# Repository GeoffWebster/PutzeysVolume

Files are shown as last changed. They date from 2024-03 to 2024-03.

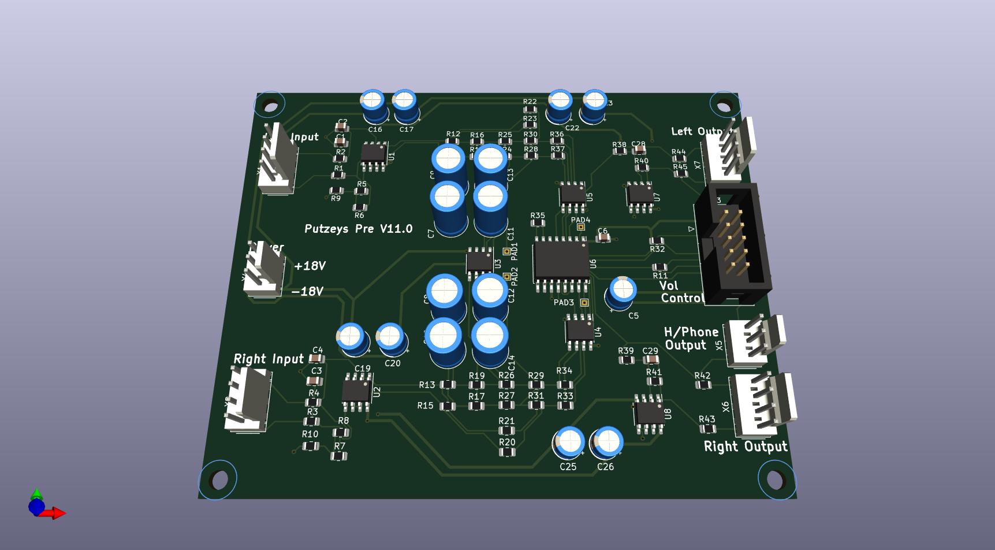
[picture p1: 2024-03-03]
putzeysPre11.jpg

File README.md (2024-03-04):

Bruno Putzeys Balanced Volume Control / MAS6116 Digital Control
===============================================================

KiCad V8 files for Bruno Putzeys Balanced Pre-amp with integrated MAS6116 Digital Volume Control Chip.

Circuit modifications from original design includes
* Addition of MAS6116 digital Stereo Volume Control in place of dual linear 10Kohm potentiometer
* Addition of inverting unity gain amplifier driver for driven signal for - output pin. Original was balanced output impedance only
* Addition of Unbalanced output (X5) to provide input to headphone amplifier

Original Bruno Putzeys preamplifier used qty 4 of LM4562 + qty 1 of TL072 (as servo)
Alternatives to LM4562 include
* OPA1642AIDR  595-OPA1642AIDR
* OPA1656ID    595-OPA1656ID

Addition of inverting amplifiers within balanced output (Vout-) adds following components into overall circuit:
U7, U8 OPA1656
R38-41 12K 0805 Thin Film
C28, C29 47pF **DNF**

Addition of unbalanced output for use by external headphone amplifier added connector X5 only.

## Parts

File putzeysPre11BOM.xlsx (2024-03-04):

Ref | Qty | Value | Mouser Part Number | Footprint | Description
C1, C2, C3, C4 | 4 | 100pF | 603-CC805FRNPO9BN101 | Capacitor_SMD:C_0805_2012Metric | 100pF 0805
C28,C29 | 2 | 47pF | - | Capacitor_SMD:C_0805_2012Metric | 47pF 0805 DNF
C5, C16, C17, C19, C20, C22, C23, C25, C26 | 9 | 22uF 63V | 710-860010572003 | Capacitor_THT:CP_Radial_D5.0mm_P2.00mm | 22uF 63V
C6 | 1 | 220nF | 603-CC0805JRX7R8B224 | Capacitor_SMD:C_0805_2012Metric | 220nF 0805
C7, C8, C9, C10, C11, C12, C13, C14 | 8 | 10uF 50V | 667-ECEA1HN100U | Capacitor_THT:C_Radial_D6.3mm_H11.0mm_P2.50mm | 10uF 50V Unpolarized capacitor
C15, C18, C21, C24, C27, C30, C31 | 7 | 1uF 50v | 603-CC1206JK7R9BB105 | Capacitor_SMD:C_1206_3216Metric | 1uF 1206
R1, R2, R3, R4 | 4 | 100 | 603-RT0805FRD07100RL | Resistor_SMD:R_0805_2012Metric | 100R Thin Film 0805
R5, R6, R7, R8 | 4 | 47K | 660-RK73H2ATTDD4702F | Resistor_SMD:R_0805_2012Metric | 47K 0805
R9, R10 | 2 | 2M2 | 603-AC0805FR-072M2L | Resistor_SMD:R_0805_2012Metric | 2M2 0805
R28, R29, R30, R31 | 4 | 10K | 603-RT0805DRE0710KL | Resistor_SMD:R_0805_2012Metric | 10K Precision Thin Film 0805
R11, R16, R17, R18, R19, R32, R35 | 7 | 10K | 660-RK73H2ATTED1002F | Resistor_SMD:R_0805_2012Metric | 10K 0805
R12, R13, R14, R15 | 4 | 12K | 660-RK73H2ATTD1202F | Resistor_SMD:R_0805_2012Metric | 12K 0805
R38, R39, R40, R41 | 4 | 12K | 603-RT0805DRE0712KL | Resistor_SMD:R_0805_2012Metric | 12K Precision Thin Film 0805
R20, R21, R22, R23, R33, R34, R36, R37 | 8 | 1K | 594-MCU0805MD1001DP5 | Resistor_SMD:R_0805_2012Metric | 1K Precision Thin Film 0805
R24, R25, R26, R27 | 4 | 220K | 660-RK73H2ATTD2203F | Resistor_SMD:R_0805_2012Metric | 220K 0805
R42, R43, R44, R45 | 4 | 22 | 660-RK73H2ATTDD22R0F | Resistor_SMD:R_0805_2012Metric | 22 0805
U1, U2, U4, U5, U7, U8 | 6 | OPA1656ID | 596-OPA1656ID | Package_SO:SOIC-8_3.9x4.9mm_P1.27mm | Alternatives are LM4562, OPA1642
U6 | 1 | MAS6116 |  |  | Available from Profusion (https://eu.profusion.uk/ro/mas6116ea1sa306)
U3 | 1 | TL072 | 595-TL072CDR | Package_SO:SOIC-8_3.9x4.9mm_P1.27mm | TL072
X1, X2, X6, X7 | 4 | 22-23-2041 | 538-22-23-2041 | Connector_Molex:Molex_KK-254_AE-6410-04A_1x04_P2.54mm_Vertical
X3 | 1 | 2-1761603-3 | 571-2-1761603-3 | Connector_IDC:IDC-Header_2x05_P2.54mm_Vertical
X4, X5 | 2 | 22-23-2031 | 538-22-23-2031 | Connector_Molex:Molex_KK-254_AE-6410-03A_1x03_P2.54mm_Vertical

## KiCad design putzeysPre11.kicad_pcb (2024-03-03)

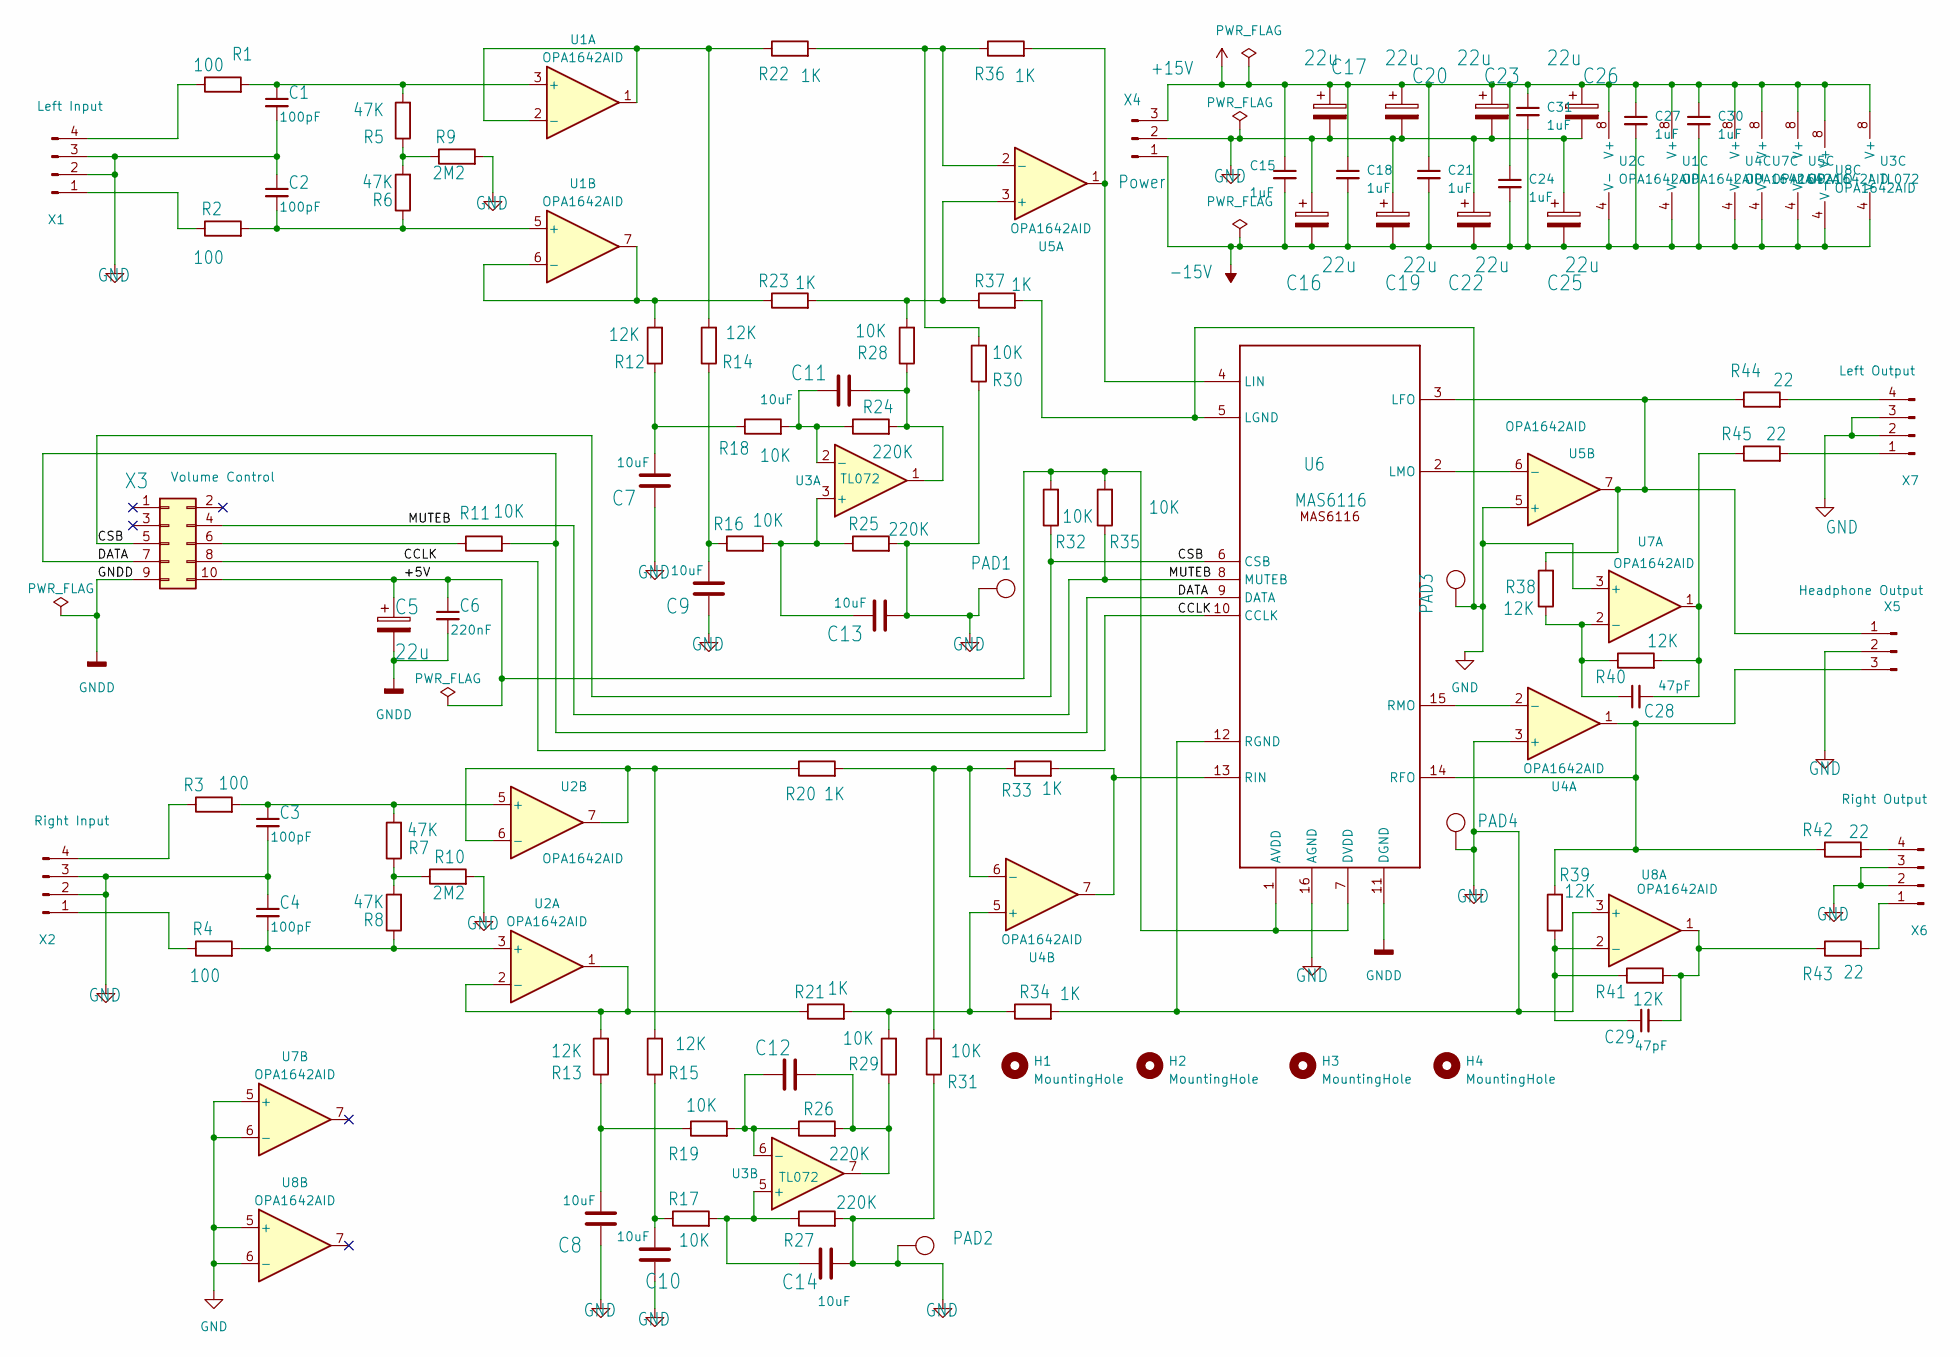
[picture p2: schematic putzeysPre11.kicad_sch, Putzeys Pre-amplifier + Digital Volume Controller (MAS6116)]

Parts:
C1, C2, C3, C4: 100pF; C_0805_2012Metric
C5, C16, C17, C19, C20, C22, C23, C25, C26: 22u; CP_Radial_D5.0mm_P2.00mm
C6: 220nF; C_0805_2012Metric
C7, C8, C9, C10, C11, C13, C14: 10uF; C_Radial_D6.3mm_H11.0mm_P2.50mm
C12: C; C_Radial_D6.3mm_H11.0mm_P2.50mm
C15, C18, C21, C24, C27, C30, C31: 1uF; C_1206_3216Metric
C28, C29: 47pF; C_0805_2012Metric
H1, H2, H3, H4: MountingHole; MountingHole_3.2mm_M3
PAD1, PAD2, PAD3, PAD4: 1,6/0,8; TestPoint_THTPad_1.0x1.0mm_Drill0.5mm
R1, R2, R3, R4: 100; R_0805_2012Metric
R5, R6, R7, R8: 47K; R_0805_2012Metric
R9, R10: 2M2; R_0805_2012Metric
R11, R16, R17, R18, R19, R28, R29, R30, R31, R32, R35: 10K; R_0805_2012Metric
R12, R13, R14, R15, R38, R39, R40, R41: 12K; R_0805_2012Metric
R20, R21, R22, R23, R33, R34, R36, R37: 1K; R_0805_2012Metric
R24, R25, R26, R27: 220K; R_0805_2012Metric
R42, R43, R44, R45: 22; R_0805_2012Metric
U1, U2, U4, U5, U8: OPA1642AID; SOIC-8_3.9x4.9mm_P1.27mm
U3: TL072
U6: MAS6116; SOIC-16W_7.5x10.3mm_P1.27mm
U7: OPA1642AID
X1: Left Input; Molex_KK-254_AE-6410-04A_1x04_P2.54mm_Vertical
X2: Right Input; Molex_KK-254_AE-6410-04A_1x04_P2.54mm_Vertical
X3: Volume Control; IDC-Header_2x05_P2.54mm_Vertical
X4: Power; Molex_KK-254_AE-6410-03A_1x03_P2.54mm_Vertical
X5: Headphone Output; Molex_KK-254_AE-6410-03A_1x03_P2.54mm_Vertical
X6: Right Output; Molex_KK-254_AE-6410-04A_1x04_P2.54mm_Vertical
X7: Left Output; Molex_KK-254_AE-6410-04A_1x04_P2.54mm_Vertical

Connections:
+18V: C15.1, C17.1, C18.1, C20.1, C21.1, C23.1, C24.1, C26.1, C27.1, C30.1, C31.1, U1.8 (V+), U2.8 (V+), U3.8 (V+), U4.8 (V+), U5.8 (V+), U7.8 (V+), U8.8 (V+), X4.3
-18V: C15.2, C16.2, C18.2, C19.2, C21.2, C22.2, C24.2, C25.2, C27.2, C30.2, C31.2, U1.4 (V-), U2.4 (V-), U3.4 (V-), U4.4 (V-), U5.4 (V-), U7.4 (V-), U8.4 (V-), X4.1
/+5V: C5.1, C6.1, R32.2, R35.2, U6.1 (AVDD), U6.7 (DVDD), X3.10
/CCLK: U6.10 (CCLK), X3.8
/CSB: R32.1, U6.6 (CSB), X3.5
/DATA: R11.2, U6.9 (DATA), X3.7
/MUTEB: R35.1, U6.8 (MUTEB), X3.4
GND: C1.2, C2.1, C3.2, C4.1, C7.1, C8.1, C9.1, C10.1, C13.1, C14.1, C16.1, C17.2, C19.1, C20.2, C22.1, C23.2, C25.1, C26.2, PAD1., PAD1.1, PAD2., PAD2.1, PAD3., PAD3.1, PAD4., PAD4.1, R9.2, R10.2, R25.2, R27.2, R30.1, R31.1, R34.2, R37.2, U4.3 (+), U5.5 (+), U6.5 (LGND), U6.12 (RGND), U6.16 (AGND), U7.3 (+), U7.5 (+), U7.6 (-), U8.3 (+), U8.5 (+), U8.6 (-), X1.2, X1.3, X2.2, X2.3, X4.2, X5.2, X6.2, X6.3, X7.2, X7.3
GNDD: C5.2, C6.2, U6.11 (DGND), X3.9
unnamed: C7.2, R12.1, R18.1
unnamed: C8.2, R13.1, R19.1
unnamed: C9.2, R14.1, R16.1
unnamed: C10.2, R15.1, R17.1
unnamed: C11.1, R24.2, R28.1, U3.1
unnamed: C12.1, R26.2, R29.1, U3.7
unnamed: C28.2, R40.2, R45.1, U7.1
unnamed: C29.2, R41.2, R43.1, U8.1
unnamed: R5.1, R6.2, R9.1
unnamed: R7.1, R8.2, R10.1
unnamed: C1.1, R1.2, R5.2, U1.3 (+)
unnamed: R14.2, R22.1, U1.1, U1.2 (-)
unnamed: C2.2, R2.2, R6.1, U1.5 (+)
unnamed: R12.2, R23.1, U1.6 (-), U1.7
unnamed: C4.2, R4.2, R8.1, U2.3 (+)
unnamed: R13.2, R21.1, U2.1, U2.2 (-)
unnamed: C3.1, R3.2, R7.2, U2.5 (+)
unnamed: R15.2, R20.1, U2.6 (-), U2.7
unnamed: C13.2, R16.2, R25.1, U3.3 (+)
unnamed: C11.2, R18.2, R24.1, U3.2 (-)
unnamed: C14.2, R17.2, R27.1, U3.5 (+)
unnamed: C12.2, R19.2, R26.1, U3.6 (-)
unnamed: U4.2 (-), U6.15 (RMO)
unnamed: R21.2, R29.2, R34.1, U4.5 (+)
unnamed: R20.2, R31.2, R33.1, U4.6 (-)
unnamed: R23.2, R28.2, R37.1, U5.3 (+)
unnamed: R22.2, R30.2, R36.1, U5.2 (-)
unnamed: U5.6 (-), U6.2 (LMO)
unnamed: R38.2, R44.1, U5.7, U6.3 (LFO), X5.1
unnamed: R36.2, U5.1, U6.4 (LIN)
unnamed: R39.2, R42.1, U4.1, U6.14 (RFO), X5.3
unnamed: R33.2, U4.7, U6.13 (RIN)
unnamed: C28.1, R38.1, R40.1, U7.2 (-)
unnamed: C29.1, R39.1, R41.1, U8.2 (-)
unnamed: R2.1, X1.1
unnamed: R1.1, X1.4
unnamed: R4.1, X2.1
unnamed: R3.1, X2.4
unnamed: R11.1, X3.6
unnamed: R43.2, X6.1
unnamed: R42.2, X6.4
unnamed: R45.2, X7.1
unnamed: R44.2, X7.4
Unconnected-(U7-Pad7): U7.7

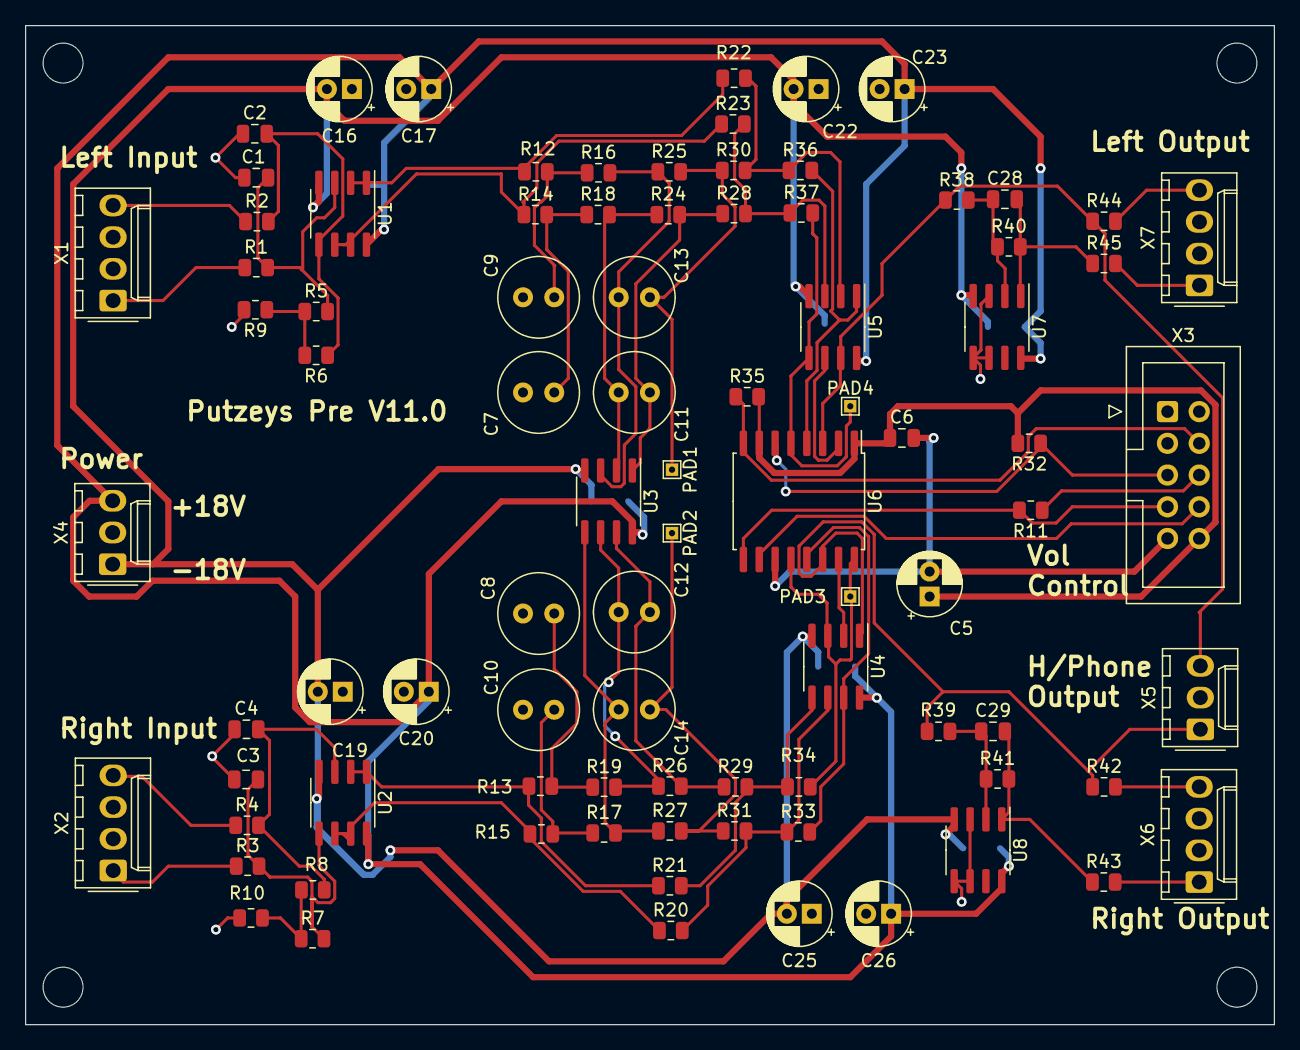
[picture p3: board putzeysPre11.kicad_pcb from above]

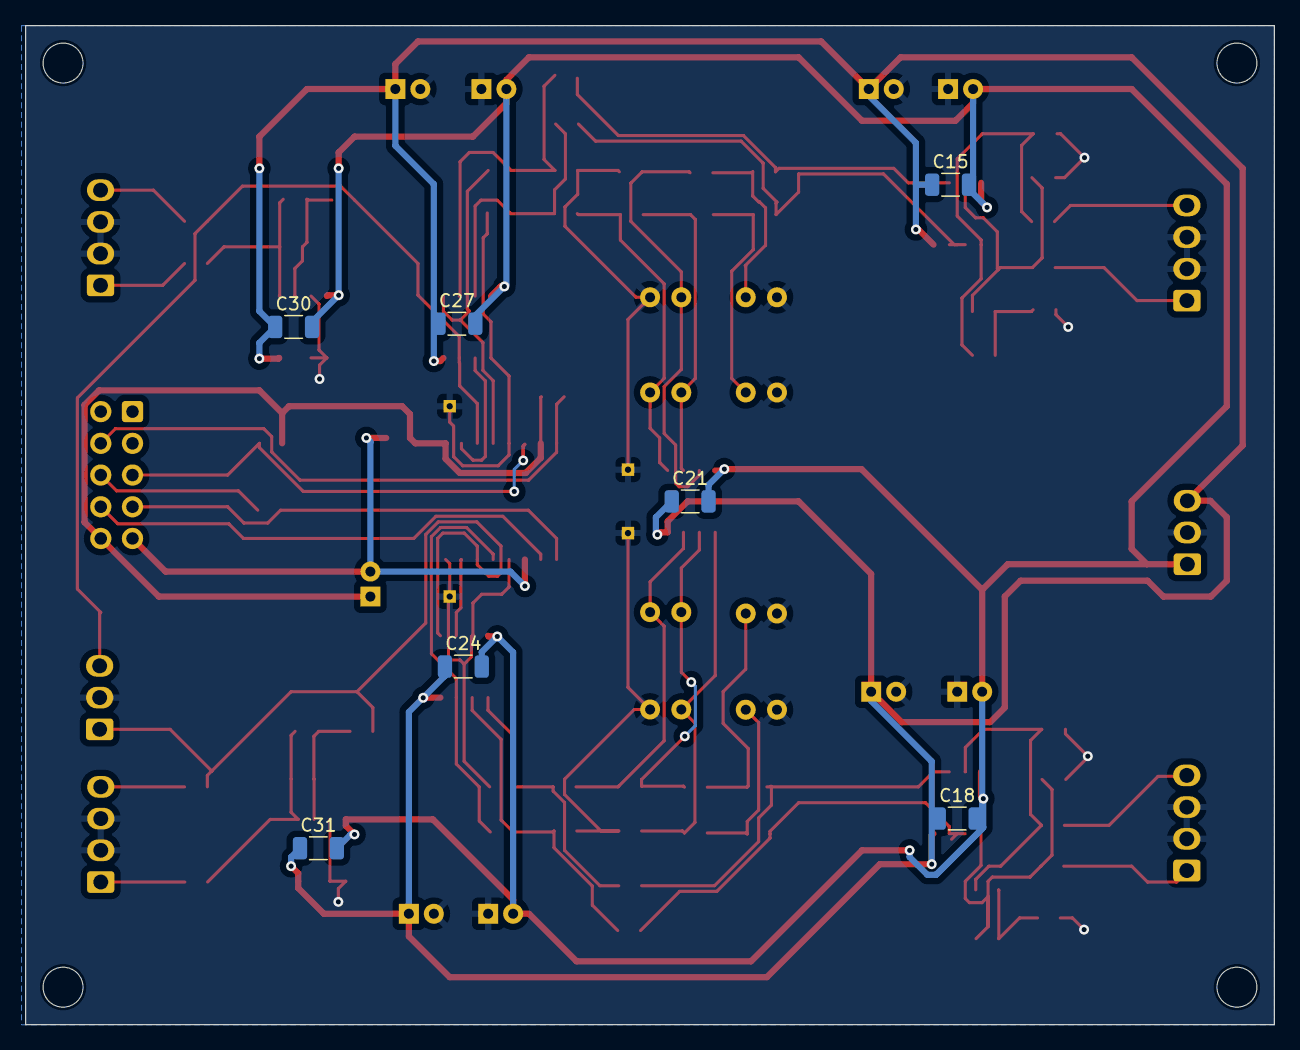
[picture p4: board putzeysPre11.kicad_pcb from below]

Board: 2 copper layers, 100.0 x 80.0 mm, 99 parts (7 on the bottom side), 52 nets.
